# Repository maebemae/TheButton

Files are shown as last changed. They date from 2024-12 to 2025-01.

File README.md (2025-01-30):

# THE BUTTON

This project aims to solve a key issue of the everyday programmer - how to safely, reliably, and in a repeatable fashion provide good feedback.

# Demonstration

[Youtube Video](https://www.youtube.com/shorts/mlwx9P0IeXQ) showing the button in action

# Using the configurator

The button will open a com port on your machine.

To configure, simply connect to it with 115200 baud rate, and follow the instructions. Do not forget to save the new settings by writing to flash, else they will be lost after a power cycle.

(On mac typically /dev/tty.usbmodem00011, on linux /dev/tty.ACME0) 
If not sure, open the com port listing (i.e. ls /dev/tty, or check the list in windows, connect the button, and see what changed)

If you have chrome, you can navigate to https://www.serialterminal.com/index.html
Or else you can use screen, minicom, or any other com 

This could be as simple as `screen /dev/tty.usbmodem00011`. To disconnect, just unplug the button

# Flashing the firmware
## Using USB DFU

1. Put The Button into DFU mode, either by
	a. Fully pressing the button and then plugging it in, or
	b. Pressing the 'boot' button and then plugging it in
2. You can use the [STM32CubeProgrammer](https://www.st.com/en/development-tools/stm32cubeprog.html) or [DfuSe](https://www.st.com/en/development-tools/stsw-stm32080.html)
3. Select USB Connection, and refresh the Port Necessarily. If you have sucessfully put your device into DFU mode, you will now see USB1 (or similar number) in the ports
4. Click connect
5. Switch to the 'Erasing & Programming' Section, load the firmware file path, and
6. Start programming
7. Disconnect and Reconnect The Button 

# Hardware

I've selected the STM32C071 as it has crystalless USB, is affordable with sufficient Flash, RAM and GPIO for potential extensions. It also has affordable dev kit [STM32 nucleo-c071rb](https://www.st.com/en/evaluation-tools/nucleo-c071rb.html) at $10 with USB-C.

Designed with Kicad, can be found under /pcb

The schematic and gerbers can be found under /pcb/output/

## KNOWN BUGS
1. The debug header silkscreen is reversed (gnd/3v3!)

# Firmware

The project is built with [STM32CubeIde](https://www.st.com/en/development-tools/stsw-stm32080.html)

Main entrypoint can be found at `The Buttoner/Core/Src/main` \
This is where the initialization generated by the STM32CubeMx IOC project happens,and also where we actually process the inputs

The second point is in `The Buttoner/libs/gbmUSBdevice/USBdev/Src/usb_app.c`, this is where we have the polled hook `HIDUpdateKB` which actually does the writing out to usb 

The gbmUSBdevice library was slightly altered and linked into the project. See [gbmUSBdevice](https://github.com/gbm-ii/gbmUSBdevice) for more details.

# Todo

1. Hardware
	1. [Not necessary] Add optional eeprom
	1. [DONE] Add hardware revision selector pins
	1. Add USB vid/pid selector (or do we just leave this in firmware?
	1. Add OpenHardware Logo 
	1. Fix the debug header silkscreen

1. Firmware
	1. [In progress] Add ondemand VCP to configure messages
	1. Apply for dedicated vid/pid from openmoko
	1. Cleanup startup so that button doesn't send messages when connected to usb

1. Project
	1. Cleanup structure 
	1. Tag versions

# License
The project in it's entirety is released under GNU GPL V3, a copy of which can be found in ./LICENSE

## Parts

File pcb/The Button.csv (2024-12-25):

Id | Designator | Footprint | Quantity | Designation | Supplier and ref
1 | R7,R10,R6,R11,R5 | R_0805_2012Metric_Pad1.20x1.40mm_HandSolder | 5 | 5k
2 | C12,C11,C13,C10 | C_0805_2012Metric_Pad1.18x1.45mm_HandSolder | 4 | 100nF
3 | C3,C4 | C_0805_2012Metric_Pad1.18x1.45mm_HandSolder | 2 | 100n
4 | C8,C9 | C_0805_2012Metric_Pad1.18x1.45mm_HandSolder | 2 | 10uF
5 | D4 | LED_0805_2012Metric_Pad1.15x1.40mm_HandSolder | 1 | USR LED 1
6 | U1 | SOT-223-3_TabPin2 | 1 | LD1117S33TR_SOT223
7 | J5 | PinSocket_1x05_P2.54mm_Vertical | 1 | Conn_01x05_Pin
8 | U5 | SOT-23-6 | 1 | USBLC6-2SC6
9 | J1 | PinSocket_1x03_P2.54mm_Vertical | 1 | Gnd
10 | D1 | LED_0805_2012Metric_Pad1.15x1.40mm_HandSolder | 1 | LED 3V
11 | R1 | R_0805_2012Metric_Pad1.20x1.40mm_HandSolder | 1 | 1K
12 | C6 | C_0805_2012Metric_Pad1.18x1.45mm_HandSolder | 1 | 4.7uF
13 | J3 | PinSocket_1x04_P2.54mm_Vertical | 1 | Extra Pins
14 | D3 | LED_0805_2012Metric_Pad1.15x1.40mm_HandSolder | 1 | USR LED 2
15 | J2 | 216989-0001_MOL | 1 | 2169890001
16 | SW8 | SW_SPST_FSMSM | 1 | SW_SPST BOOT
17 | C7 | C_0805_2012Metric_Pad1.18x1.45mm_HandSolder | 1 | 4.7Uf
18 | U2 | LQFP-32_7x7mm_P0.8mm | 1 | STM32C071KBTx
19 | J4 | PinSocket_1x04_P2.54mm_Vertical | 1 | Buttons

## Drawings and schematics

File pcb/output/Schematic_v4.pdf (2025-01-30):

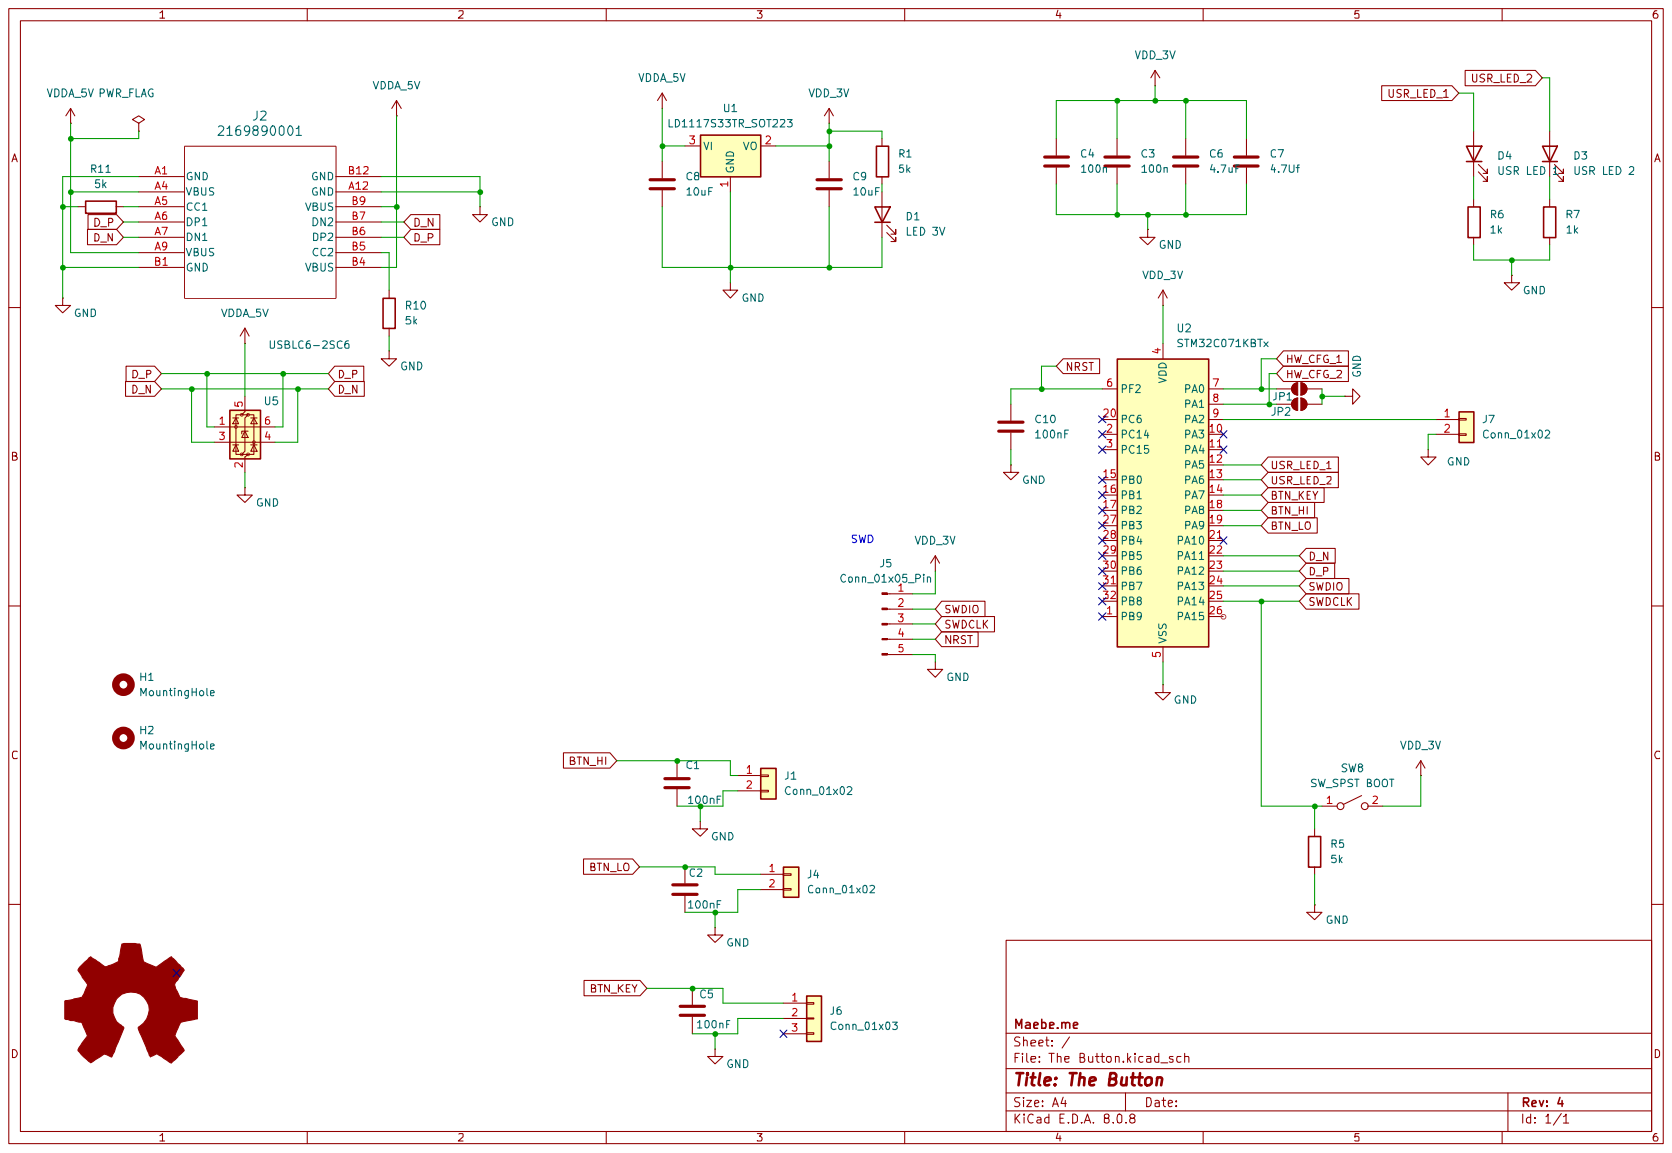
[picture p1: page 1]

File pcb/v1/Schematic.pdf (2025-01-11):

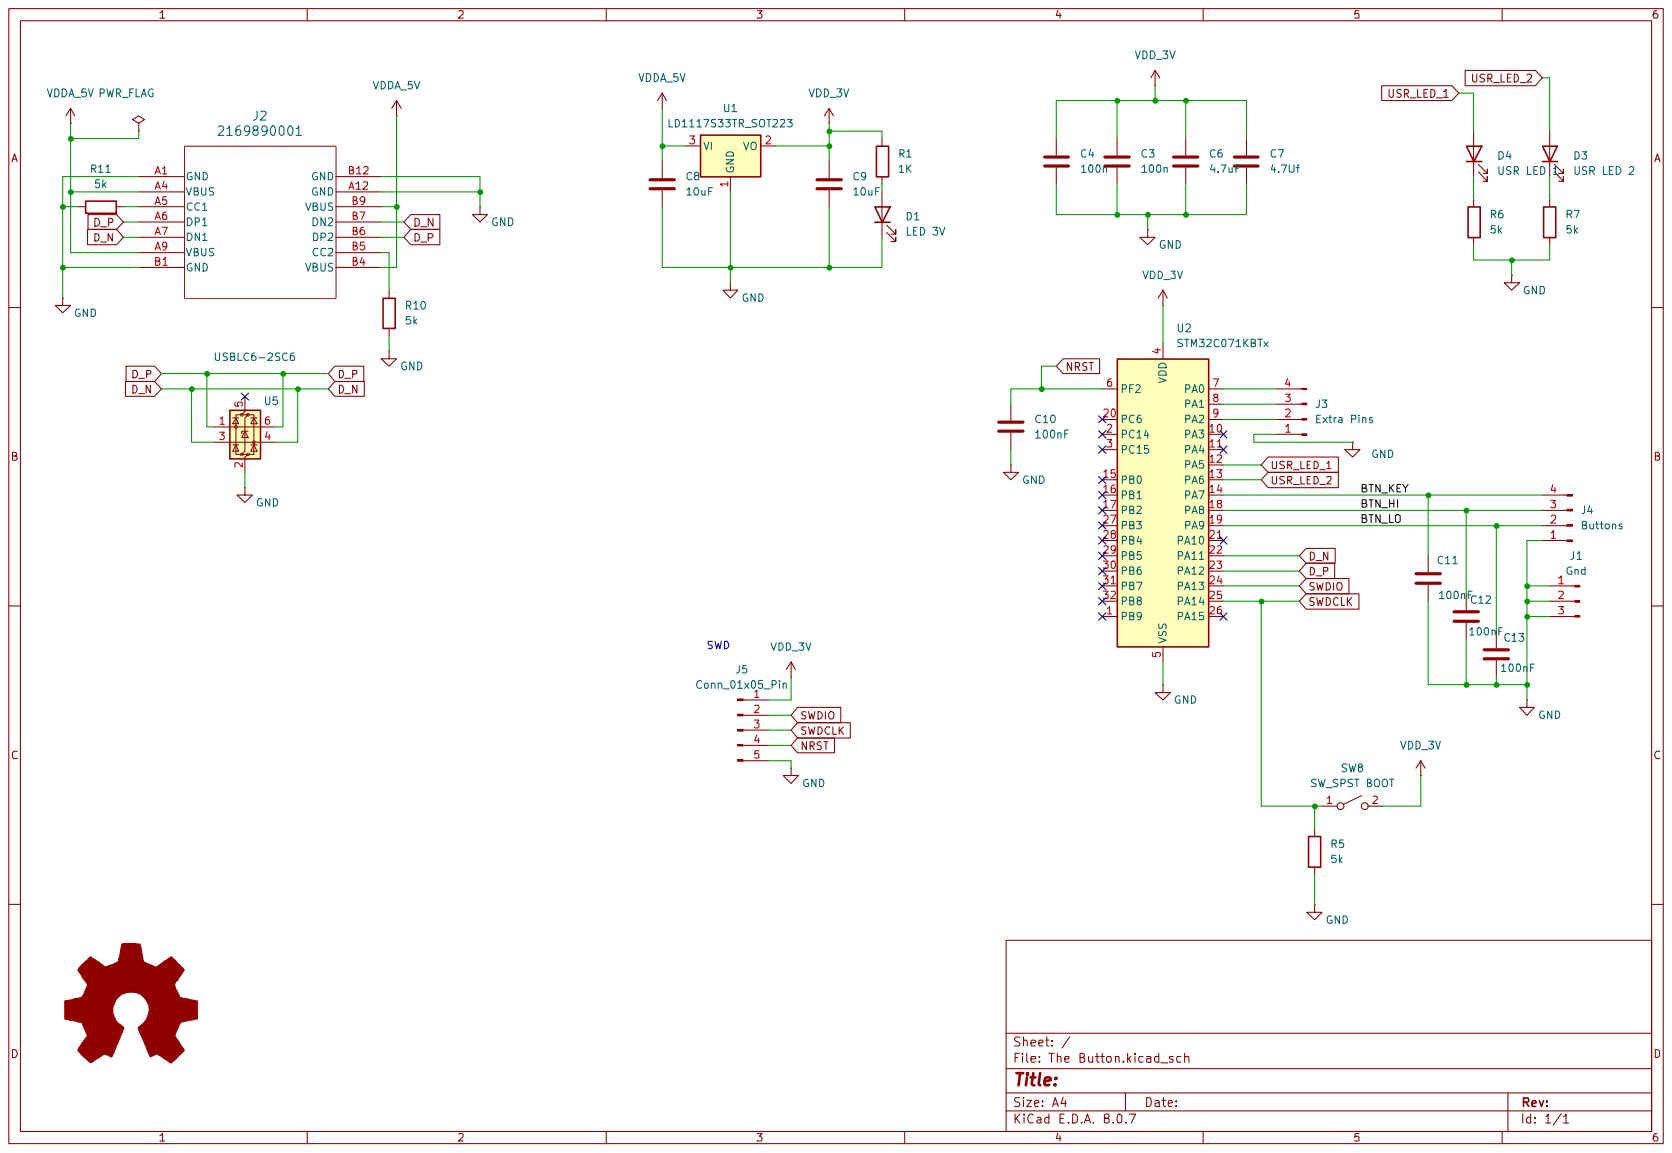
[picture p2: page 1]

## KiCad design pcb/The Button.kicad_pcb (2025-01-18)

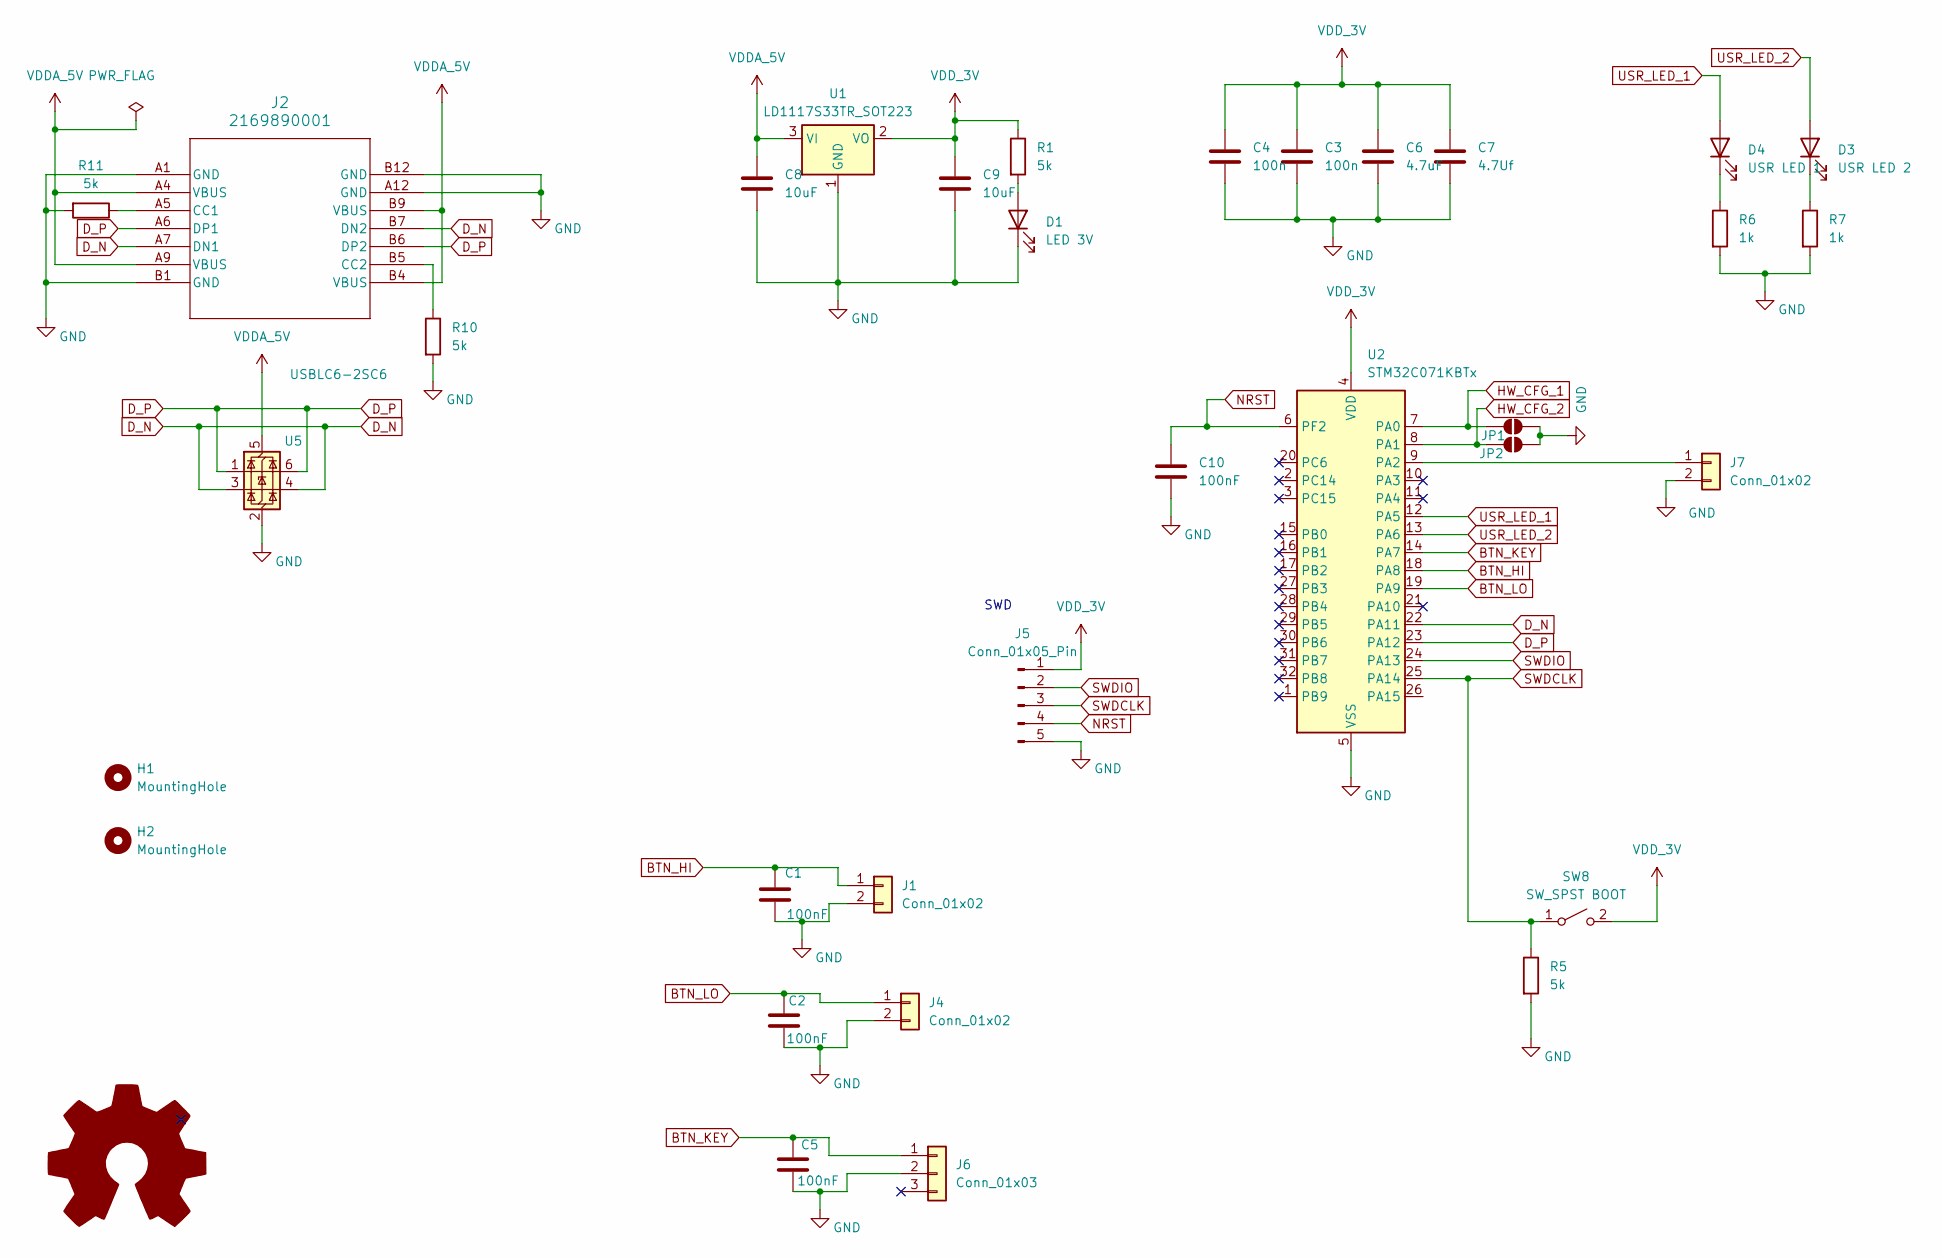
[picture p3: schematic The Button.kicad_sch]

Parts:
C1, C2, C5, C10: 100nF; C_0805_2012Metric_Pad1.18x1.45mm_HandSolder
C3, C4: 100n; C_0805_2012Metric_Pad1.18x1.45mm_HandSolder
C6: 4.7uF; C_0805_2012Metric_Pad1.18x1.45mm_HandSolder
C7: 4.7Uf; C_0805_2012Metric_Pad1.18x1.45mm_HandSolder
C8, C9: 10uF; C_0805_2012Metric_Pad1.18x1.45mm_HandSolder
D1: LED 3V; LED_0805_2012Metric_Pad1.15x1.40mm_HandSolder
D3: USR LED 2; LED_0805_2012Metric_Pad1.15x1.40mm_HandSolder
D4: USR LED 1; LED_0805_2012Metric_Pad1.15x1.40mm_HandSolder
H1, H2: MountingHole; MountingHole_3.2mm_M3
J1, J4: Conn_01x02; JST_XH_B2B-XH-AM_1x02_P2.50mm_Vertical
J2: 2169890001; 216989-0001_MOL
J5: Conn_01x05_Pin; PinSocket_1x05_P2.54mm_Vertical
J6: Conn_01x03; JST_XH_B3B-XH-AM_1x03_P2.50mm_Vertical
J7: Conn_01x02; PinHeader_1x02_P2.54mm_Vertical
JP1, JP2: SolderJumper_2_Open; SolderJumper-2_P1.3mm_Open_TrianglePad1.0x1.5mm
R1, R5, R10, R11: 5k; R_0805_2012Metric_Pad1.20x1.40mm_HandSolder
R6, R7: 1k; R_0805_2012Metric_Pad1.20x1.40mm_HandSolder
SW8: SW_SPST BOOT; SW_SPST_FSMSM
U1: LD1117S33TR_SOT223; SOT-223-3_TabPin2
U2: STM32C071KBTx; LQFP-32_7x7mm_P0.8mm
U5: USBLC6-2SC6; SOT-23-6

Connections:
BTN_HI: C1.1, J1.1, U2.18 (PA8)
BTN_KEY: C5.1, J6.1, U2.14 (PA7)
BTN_LO: C2.1, J4.1, U2.19 (PA9)
D_N: J2.A7 (DN1), J2.B7 (DN2), U2.22 (PA11), U5.3 (I/O2), U5.4 (I/O2)
D_P: J2.A6 (DP1), J2.B6 (DP2), U2.23 (PA12), U5.1 (I/O1), U5.6 (I/O1)
GND: C1.2, C2.2, C3.2, C4.2, C5.2, C6.2, C7.2, C8.2, C9.2, C10.2, D1.1 (K), J1.2, J2.A1 (GND), J2.A12 (GND), J2.B1 (GND), J2.B12 (GND), J4.2, J5.5, J6.2, J7.2, JP1.1 (A), JP2.1 (A), R5.2, R6.2, R7.2, R10.2, R11.2, U1.1 (GND), U2.5 (VSS), U5.2 (GND)
HW_CFG_1: JP1.2 (B), U2.7 (PA0)
HW_CFG_2: JP2.2 (B), U2.8 (PA1)
NRST: C10.1, J5.4, U2.6 (PF2)
unnamed: D1.2 (A), R1.2
unnamed: D3.1 (K), R7.1
unnamed: D4.1 (K), R6.1
unnamed: J2.A5 (CC1), R11.1
unnamed: J2.B5 (CC2), R10.1
unnamed: J7.1, U2.9 (PA2)
SWDCLK: J5.3, R5.1, SW8.1 (A), U2.25 (PA14)
SWDIO: J5.2, U2.24 (PA13)
USR_LED_1: D4.2 (A), U2.12 (PA5)
USR_LED_2: D3.2 (A), U2.13 (PA6)
VDDA_5V: C8.1, J2.A4 (VBUS), J2.A9 (VBUS), J2.B4 (VBUS), J2.B9 (VBUS), U1.3 (VI), U5.5 (VBUS)
VDD_3V: C3.1, C4.1, C6.1, C7.1, C9.1, J5.1, R1.1, SW8.2 (B), U1.2 (VO), U2.4 (VDD)

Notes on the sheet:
SWD

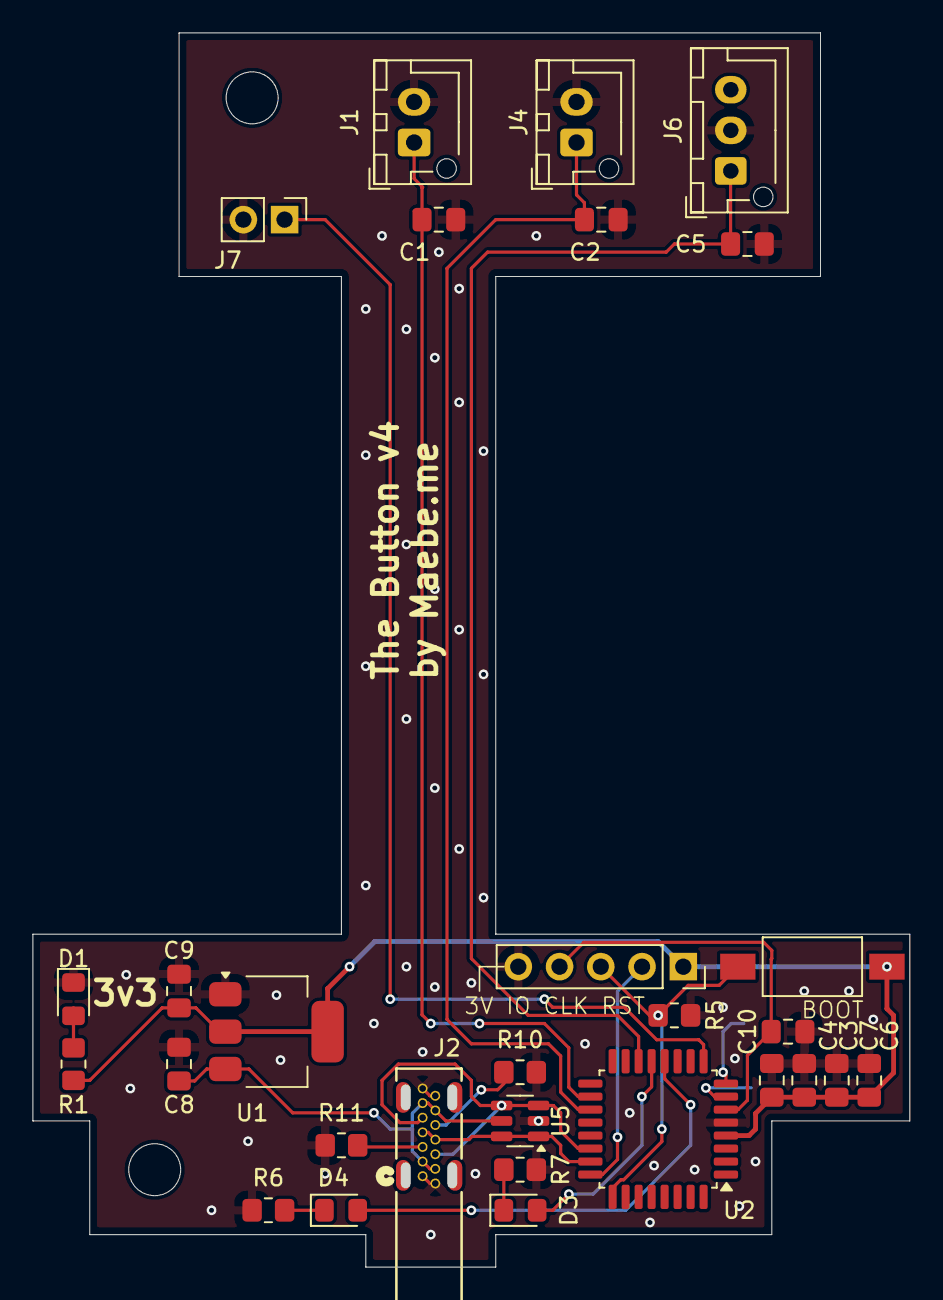
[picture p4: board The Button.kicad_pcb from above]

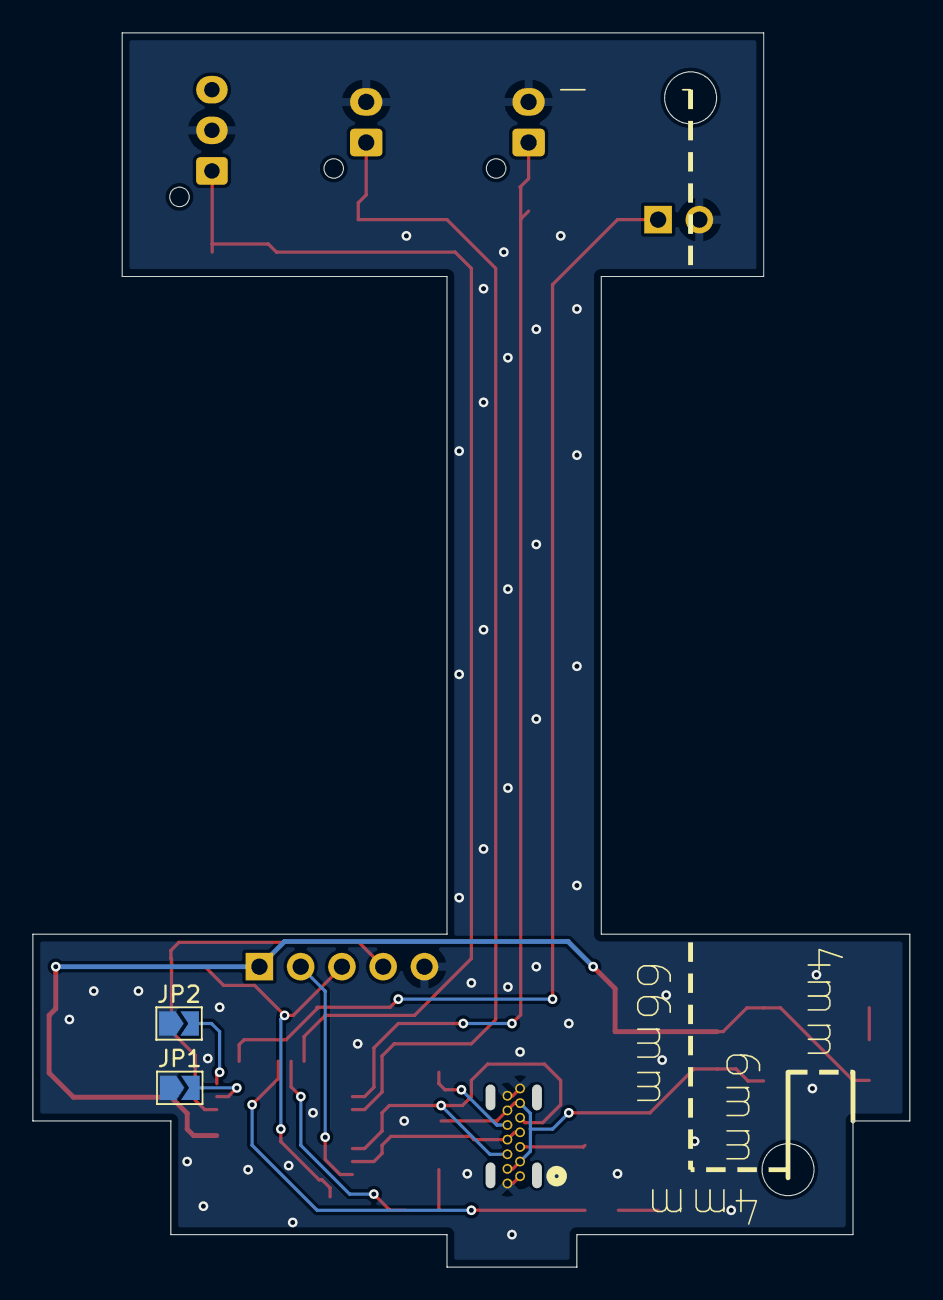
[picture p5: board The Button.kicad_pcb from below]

Board: 2 copper layers, 54.0 x 76.0 mm, 33 parts (2 on the bottom side), 21 nets.

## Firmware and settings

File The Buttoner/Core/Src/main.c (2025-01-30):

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
/* Includes ------------------------------------------------------------------*/
#include "main.h"


__IO uint32_t BspButtonState = BUTTON_RELEASED;

CRC_HandleTypeDef hcrc;

TIM_HandleTypeDef htim2;

PCD_HandleTypeDef hpcd_USB_DRD_FS;

/* USER CODE BEGIN PV */
bool main_initialized = false;
/* USER CODE END PV */

void SystemClock_Config(void);
static void MX_GPIO_Init(void);
static void MX_USB_PCD_Init(void);
static void MX_TIM2_Init(void);
static void MX_FLASH_Init(void);
static void MX_CRC_Init(void);
/* USER CODE BEGIN 0 */

void start_button_timer() {
	htim2.Instance->CNT = 0; // initial run timers seems to be running alr
	HAL_TIM_Base_Start_IT(&htim2);
}

bool enable_nsfw(){

	return (HAL_GPIO_ReadPin(KEY_SWITCH_GPIO_Port, KEY_SWITCH_Pin) == 0);
}

typedef enum Press_Typedef {
	Hardest_Press = 0,
	Hard_Press,
	Medium_Press,
	Soft_Press
} Press_Typedef;

void print_out(Press_Typedef severity){

	if(enable_nsfw())
	{
//		hid_print_text(&NSFW_TEXTS[severity][0]);
		hid_print_text((const char*)messages_get_current()->bank_a[severity]);
	} else {
//		hid_print_text(&SFW_TEXTS[severity][0]);
		hid_print_text((const char*)messages_get_current()->bank_b[severity]);
	}
}

Press_Typedef duration_to_press(uint32_t pressDurationUs) {
	Press_Typedef severity;
	if (pressDurationUs < HARD_MED_LIMIT_US) {
		severity = Hardest_Press;
	} else if (pressDurationUs < MED_SOFT_LIMIT_US) {
		severity = Hard_Press;
	} else if (pressDurationUs < SOFT_LIMIT_US) {
		severity = Medium_Press;
	} else {
		severity = Soft_Press;
	}
	return severity;


}

uint32_t end_button_timer() {
		uint32_t currentCount = htim2.Instance->CNT;
		HAL_TIM_Base_Stop_IT(&htim2);
		uint32_t durationUs = currentCount / 12;
		htim2.Instance->CNT = 0; // clear the counter so we can't double trigger
		return durationUs;
}

void HAL_GPIO_EXTI_Rising_Callback(uint16_t GPIO_Pin) {
	if(!main_initialized)
	{
		return;
	}
	if (GPIO_Pin == BUTTON_LO_Pin) {
		BSP_LED_Off(LED_GREEN);
	}
	if (GPIO_Pin == BUTTON_HI_Pin) {
		BSP_LED_Off(LED_BLUE);
		HAL_GPIO_WritePin(USR_LED2_GPIO_Port, USR_LED2_Pin, GPIO_PIN_RESET);
		uint32_t pressDurationUs = end_button_timer();
		if(pressDurationUs > 0){
			// The button wasn't pressed hard enough to trigger the lower switch, thus consider this the lowest severity
			print_out(Soft_Press);
		}
	}
	if (GPIO_Pin == KEY_SWITCH_Pin) {
		  GPIO_InitTypeDef GPIO_InitStruct = {0};
		  GPIO_InitStruct.Pin = KEY_SWITCH_LED_Pin;
		  GPIO_InitStruct.Mode = GPIO_MODE_IT_RISING;
		  GPIO_InitStruct.Pull = GPIO_PULLDOWN; // cheating by using internal resistor instead of push/pull -> LED OFF
		  HAL_GPIO_Init(KEY_SWITCH_LED_GPIO_Port, &GPIO_InitStruct);
	}

}

void HAL_GPIO_EXTI_Falling_Callback(uint16_t GPIO_Pin) {
	if(!main_initialized)
	{
		return;
	}

	if (GPIO_Pin == BUTTON_LO_Pin) {
		BSP_LED_On(LED_GREEN);
		uint32_t pressDurationUs = end_button_timer();
		if(pressDurationUs > 0)
		{
			Press_Typedef press = duration_to_press(pressDurationUs);
			print_out(press);
		}
	}
	if (GPIO_Pin == BUTTON_HI_Pin) {
		BSP_LED_On(LED_BLUE);
		HAL_GPIO_WritePin(USR_LED2_GPIO_Port, USR_LED2_Pin, GPIO_PIN_SET);
		start_button_timer();
	}
	if (GPIO_Pin == KEY_SWITCH_Pin) {
		  GPIO_InitTypeDef GPIO_InitStruct = {0};
		  GPIO_InitStruct.Pin = KEY_SWITCH_LED_Pin;
		  GPIO_InitStruct.Mode = GPIO_MODE_IT_RISING;
		  GPIO_InitStruct.Pull = GPIO_PULLUP; // cheating by using internal resistor instead of push/pull
		  HAL_GPIO_Init(KEY_SWITCH_LED_GPIO_Port, &GPIO_InitStruct);
	}
}

/* USER CODE END 0 */

/**
  * @brief  The application entry point.
  * @retval int
  */
int main(void)
{

  /* MCU Configuration--------------------------------------------------------*/

  /* Reset of all peripherals, Initializes the Flash interface and the Systick. */
  HAL_Init();

  /* Configure the system clock */
  SystemClock_Config();

  /* Initialize all configured peripherals */
  MX_GPIO_Init();
  MX_USB_PCD_Init();
  MX_TIM2_Init();
  MX_FLASH_Init();
  MX_CRC_Init();
  /* USER CODE BEGIN 2 */

  if((HAL_GPIO_ReadPin(BUTTON_HI_GPIO_Port, BUTTON_HI_Pin) == 0 && HAL_GPIO_ReadPin(BUTTON_LO_GPIO_Port, BUTTON_LO_Pin) == 0)){
	  // enter bootloader
	  JumpToBootloader();
  }


  /* USER CODE END 2 */

  /* Initialize leds */
  BSP_LED_Init(LED_GREEN);
  BSP_LED_Init(LED_BLUE);

  /* Initialize USER push-button, will be used to trigger an interrupt each time it's pressed.*/
  BSP_PB_Init(BUTTON_USER, BUTTON_MODE_EXTI);

  /* USER CODE BEGIN BSP */

	/* -- Sample board code to switch on leds ---- */

	USBapp_Init();

	main_initialized = true;
  /* USER CODE END BSP */

  /* Infinite loop */
  /* USER CODE BEGIN WHILE */
	while (1) {
		// just wait for interrupts
		__WFI();

//    /* -- Sample board code for User push-button in interrupt mode ---- */
//    if (BspButtonState == BUTTON_PRESSED)
//    {
//      /* Update button state */
//      BspButtonState = BUTTON_RELEASED;
//      /* -- Sample board code to toggle leds ---- */
//      BSP_LED_Toggle(LED_GREEN);
//      BSP_LED_Toggle(LED_BLUE);
//
//      /* ..... Perform your action ..... */
//    }
    /* USER CODE END WHILE */

    /* USER CODE BEGIN 3 */
	}
  /* USER CODE END 3 */
}

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
/**
  * @brief  BSP Push Button callback
  * @param  Button Specifies the pressed button
  * @retval None
  */
void BSP_PB_Callback(Button_TypeDef Button)
{
  if (Button == BUTTON_USER)
  {
    BspButtonState = BUTTON_PRESSED;
  }
}

/**
  * @brief  This function is executed in case of error occurrence.
  * @retval None
  */
void Error_Handler(void)
{
  /* USER CODE BEGIN Error_Handler_Debug */
	/* User can add his own implementation to report the HAL error return state */
	__disable_irq();
	while (1) {
	}
  /* USER CODE END Error_Handler_Debug */
}

#ifdef  USE_FULL_ASSERT
/**
  * @brief  Reports the name of the source file and the source line number
  *         where the assert_param error has occurred.
  * @param  file: pointer to the source file name
  * @param  line: assert_param error line source number
  * @retval None
  */
void assert_failed(uint8_t *file, uint32_t line)
{
  /* USER CODE BEGIN 6 */
  /* User can add his own implementation to report the file name and line number,
     ex: printf("Wrong parameters value: file %s on line %d\r\n", file, line) */
  /* USER CODE END 6 */
}
#endif /* USE_FULL_ASSERT */

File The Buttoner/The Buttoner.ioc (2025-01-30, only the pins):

Mcu.UserName=STM32C071RBTx
PA13.Signal=DEBUG_SWDIO
PA14-BOOT0.Signal=DEBUG_SWCLK
PA2.GPIO_Label=KEY_SWITCH_LED
PA2.Signal=GPXTI2
PA5.Signal=GPIO_Output
PA6.GPIO_Label=USR_LED2
PA6.Signal=GPIO_Output
PA7.GPIO_Label=KEY_SWITCH
PA7.Signal=GPXTI7
PA8.GPIO_Label=BUTTON_LO
PA8.Signal=GPXTI8
PC13.Signal=GPIO_Input
PC9.Signal=GPIO_Output

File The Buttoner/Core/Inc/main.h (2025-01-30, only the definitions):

#define KEY_SWITCH_LED_Pin GPIO_PIN_2
#define KEY_SWITCH_LED_GPIO_Port GPIOA
#define USR_LED2_Pin GPIO_PIN_6
#define USR_LED2_GPIO_Port GPIOA
#define KEY_SWITCH_Pin GPIO_PIN_7
#define KEY_SWITCH_GPIO_Port GPIOA
#define KEY_SWITCH_EXTI_IRQn EXTI4_15_IRQn
#define BUTTON_LO_Pin GPIO_PIN_8
#define BUTTON_LO_GPIO_Port GPIOA
#define BUTTON_LO_EXTI_IRQn EXTI4_15_IRQn
#define BUTTON_HI_Pin GPIO_PIN_9
#define BUTTON_HI_GPIO_Port GPIOA
#define BUTTON_HI_EXTI_IRQn EXTI4_15_IRQn
#define HARD_MED_LIMIT_US 2000
#define MED_SOFT_LIMIT_US 10000
#define SOFT_LIMIT_US 50000

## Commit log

2024-12-23 Initial, got working usb hid example from gbmUSBDevice; also got button interrupts working (disabled)
2024-12-23 The use the external button
2024-12-25 Adding kicad layouts
    [The Button-B_Cu.gbr, The Button-B_Mask.gbr, The Button-B_Paste.gbr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]
2024-12-27 Move character conversion to separate file
    [The Button-B_Cu.gbr, The Button-B_Mask.gbr, The Button-B_Paste.gbr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]
2024-12-30 Timer nicely debounced
2024-12-30 Disable leds on startup
2025-01-01 Bootloader on button press
2025-01-01 Add LEDs
2025-01-04 Enterprise compliant button
2025-01-08 Clean up project structure
    [The Button-B_Cu.gbr, The Button-B_Mask.gbr, The Button-B_Paste.gbr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]
2025-01-09 Add missing files
    [The Button.csv, The Button.kicad_pcb, The Button.kicad_sch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]
2025-01-11 Check in schematic
    [The Button.csv, The Button.kicad_pcb, The Button.kicad_sch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]
2025-01-11 Add the files
    [The Button.csv, The Button.kicad_pcb, The Button.kicad_sch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]
2025-01-12 Can write to flash, but there's an error
    [user_data.c]
2025-01-16 Update pcb schematic to v3, layout pending
    [The Button.kicad_pcb, The Button.kicad_sch]
2025-01-17 Routing of pcb v3
    [The Button.kicad_pcb, The Button.kicad_sch]
2025-01-17 Added solder jumpers for hw config
    [The Button-B_Cu.gbr, The Button-B_Mask.gbr, The Button-B_Paste.gbr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]
2025-01-17 Some minor tweaks, bump to v4
    [The Button-B_Cu.gbr, The Button-B_Mask.gbr, The Button-B_Paste.gbr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]
2025-01-30 Add in printed schematic
2025-01-30 Reformat pcb layout and update readme
    [The Button-B_Cu.gbr, The Button-B_Mask.gbr, The Button-B_Paste.gbr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]
2025-01-30 No longer printing on connection
    [The Button.kicad_sch]

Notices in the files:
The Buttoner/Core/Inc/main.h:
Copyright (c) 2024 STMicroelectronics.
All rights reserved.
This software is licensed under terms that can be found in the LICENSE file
